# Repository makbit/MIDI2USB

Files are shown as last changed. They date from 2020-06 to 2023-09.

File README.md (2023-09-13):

# MIDI2USB - Free and improved MIDI to USB Converter (v.1.3 Nov 2022)








This device is designed to connect various musical instruments to a PC via the USB Fullspeed port. This is an improved version of the chinese **USB2MIDI** adapter in the same case. There are: 1 IN port, 1 OUT port, 16 channels/instruments, Plug-and-Play feature, Build-in drivers. The adapter is compatible with Windows (32-bit, 64-bit) and was tested with MIDI-OX, MuseScore, Cubase, etc.

The device is based on Silicon Laboratories 8-bit 8051 MCU [EFM8UB20F32](https://www.silabs.com/mcu/8-bit/efm8-universal-bee/device.efm8ub20f32g-qfp32), (avg. price $2). This MCU has Fullspeed USB controller and adjustable internal oscillator (0.25%). You can use any compatible MCU, for example [C8051F380](https://www.silabs.com/mcu/8-bit/c8051f38x/device.c8051f380-gq).

### Advantages of this MIDI2USB adapter:
* Open and clean source code with comments;
* Compliant to hardware and software [MIDI Specification 1.0](https://www.midi.org/specifications-old/item/the-midi-1-0-specification);
* All electronic components are available in your local shop;
* I use it myself.
* MIT License

The [`Hardware`](Hardware) folder contains Eagle CAD 9.0 schematics files, board file and component library. The .BRD file can be sent to your favourite PCB manufacturer. The board schematics can be found in the[`Hardware/Efm8Midi.png`](Hardware/Efm8Midi.png) file.

In the [`Firmware`](Firmware) folder you will find all C-source files for this project. Files from SiLabs SDK are located in the EFM8 subfolder. The project was developed with the [IAR Embedded Workbench IDE 8051](https://www.iar.com/iar-embedded-workbench/#!?architecture=8051). I beleive the source code is compatible with the [Keil uVision PK51](https://www.keil.com/c51/pk51kit.asp).

### Some pictures of this MIDI2USB converter :cool:
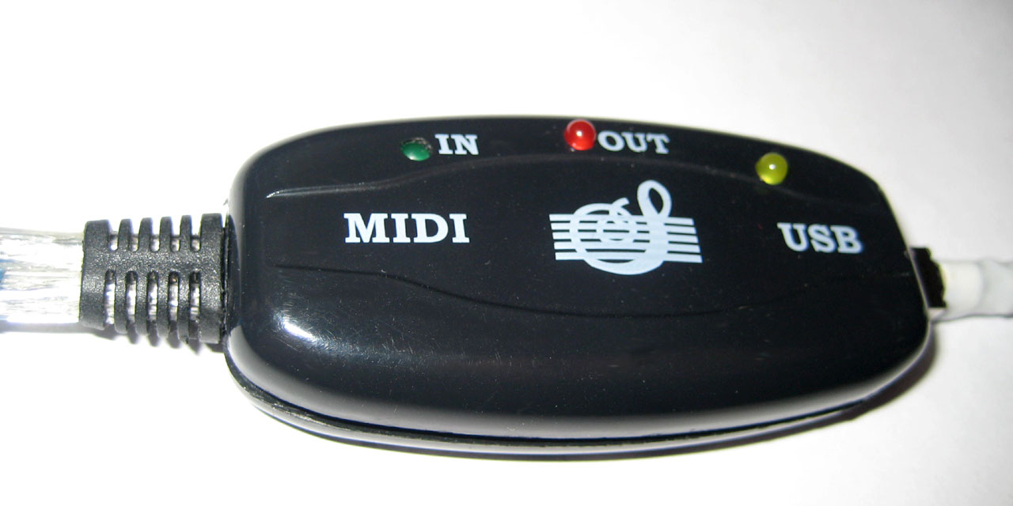
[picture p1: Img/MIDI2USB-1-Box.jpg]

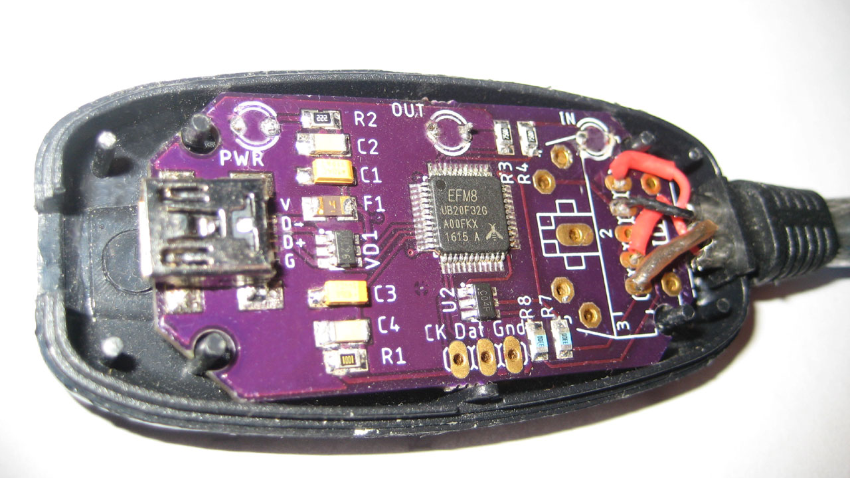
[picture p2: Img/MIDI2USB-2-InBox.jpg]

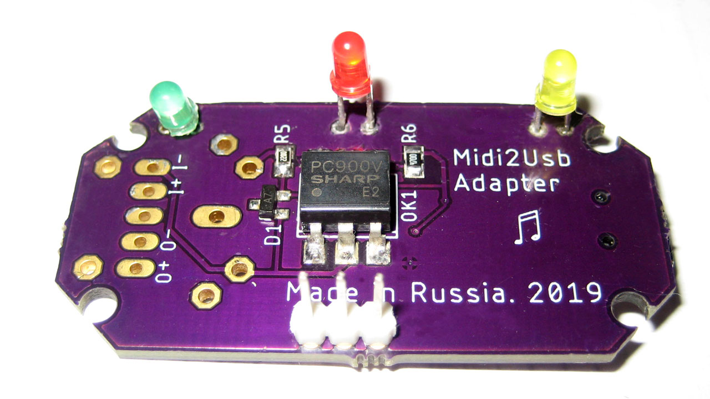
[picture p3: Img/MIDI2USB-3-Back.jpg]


### TODO :pen:
- [x] Switch to UART#1 with FIFO buffer (done);
- [x] Test and improve SysEx handler (done);
- [x] Added Real-Time Message handler (done/test required);
- [ ] Move all components to one side;
- [ ] Add 4-pin header to optionaly solder USB cable;
- [ ] Find a sponsor :smile:

[GitHub readme tips&tricks](https://help.github.com/articles/basic-writing-and-formatting-syntax/)

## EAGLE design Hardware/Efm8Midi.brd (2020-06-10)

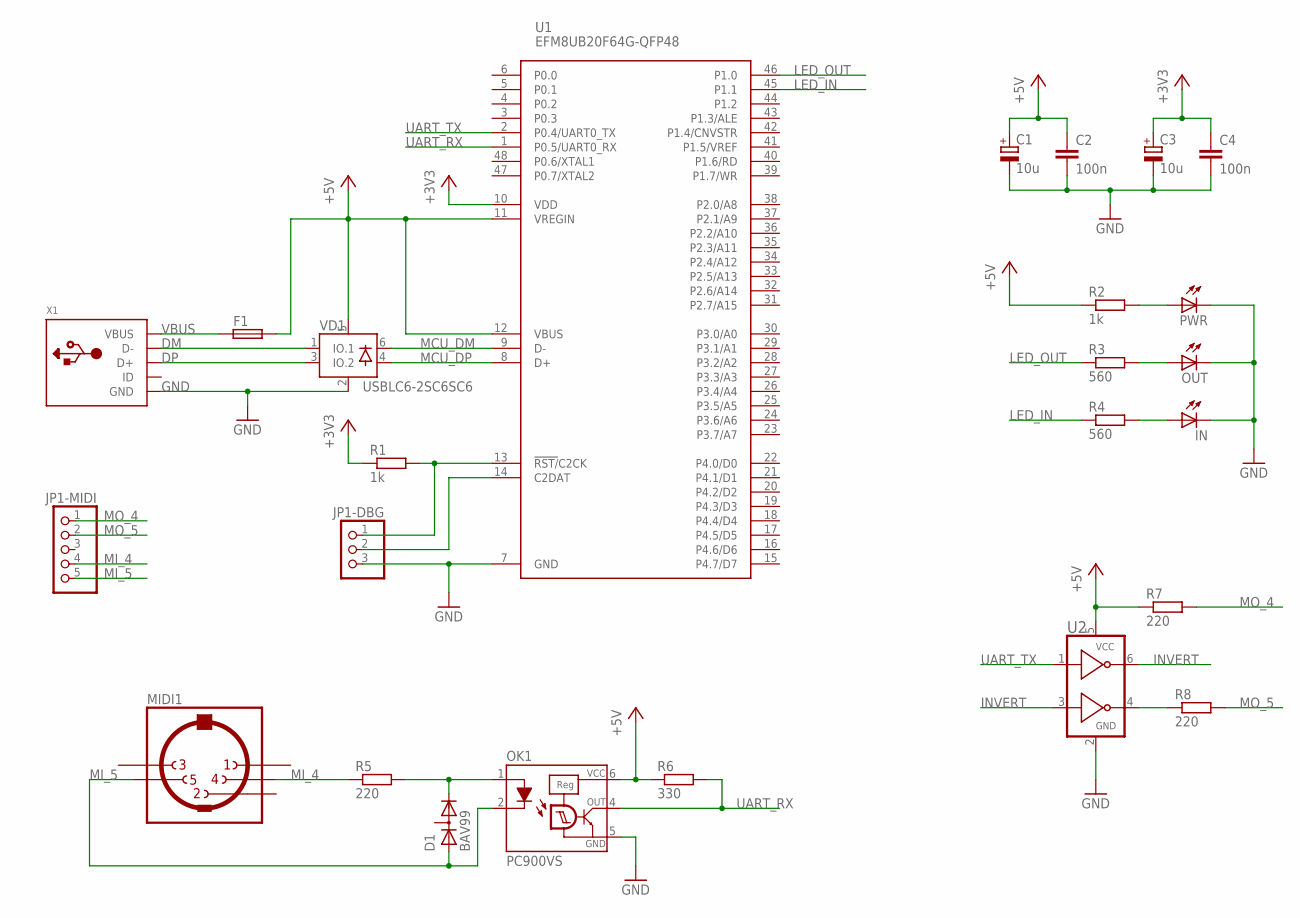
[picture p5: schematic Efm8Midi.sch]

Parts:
C1, C3: 10u; CT3216
C2, C4: 100n; C1206
D1: BAV99; SOT23
F1: MF-NSMF; RCL-1206
IN: LED3MM
JP1-DBG: PINHD-1X3; 1X03
JP1-MIDI: PINHD-1X5; 1X05
MIDI1: MIDIJACK; MIDI-CP-2350
OK1: PC900VS; DIL6-SMD
OUT: LED3MM
PWR: LED3MM
R1, R2: 1k; R0805
R3, R4: 560; R0805
R5, R7, R8: 220; R0805
R6: 330; R0805
U1: EFM8UB20F64G-QFP48; QFP48-7X7-0P5MM
U2: 74LVC2G04SOT-23-6-DBV; SOT-23-290X160-DBV
VD1: USBLC6-2SC6SC6; SOT-23-6L
X1: MINI-USB-B32005-301; USB-MINI-B

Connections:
+3V3: C3.+, C4.1, R1.1, U1.10 (VDD)
+5V: C1.+, C2.1, F1.2, OK1.6 (VCC), R2.1, R6.1, R7.1, U1.11 (VREGIN), U1.12 (VBUS), U2.5 (VCC), VD1.5 (VBUS)
DM: VD1.1 (IO.1), X1.D-
DP: VD1.3 (IO.2), X1.D+
GND: C1.-, C2.2, C3.-, C4.2, IN.K (C), JP1-DBG.3, OK1.5 (GND), OUT.K (C), PWR.K (C), U1.7 (GND), U2.2 (GND), VD1.2 (GND), X1.GND
INVERT: U2.3 (A2), U2.6 (Y1)
LED_IN: R4.1, U1.45 (P1.1)
LED_OUT: R3.1, U1.46 (P1.0)
MCU_DM: U1.9 (D-), VD1.6 (IO_1)
MCU_DP: U1.8 (D+), VD1.4 (IO_2)
MI_4: JP1-MIDI.4, MIDI1.4, R5.1
MI_5: D1.1 (A), JP1-MIDI.5, MIDI1.5, OK1.2 (C)
MO_4: JP1-MIDI.1, R7.2
MO_5: JP1-MIDI.2, R8.2
unnamed: IN.A, R4.2
unnamed: JP1-DBG.1, R1.2, U1.13 (!RST/!C2CK)
unnamed: PWR.A, R2.2
unnamed: R8.1, U2.4 (Y2)
unnamed: D1.2 (C), OK1.1 (A), R5.2
unnamed: JP1-DBG.2, U1.14 (C2DAT)
unnamed: OUT.A, R3.2
UART_RX: OK1.4 (OUT), R6.2, U1.1 (P0.5/UART0_RX)
UART_TX: U1.2 (P0.4/UART0_TX), U2.1 (A1)
VBUS: F1.1, X1.VBUS

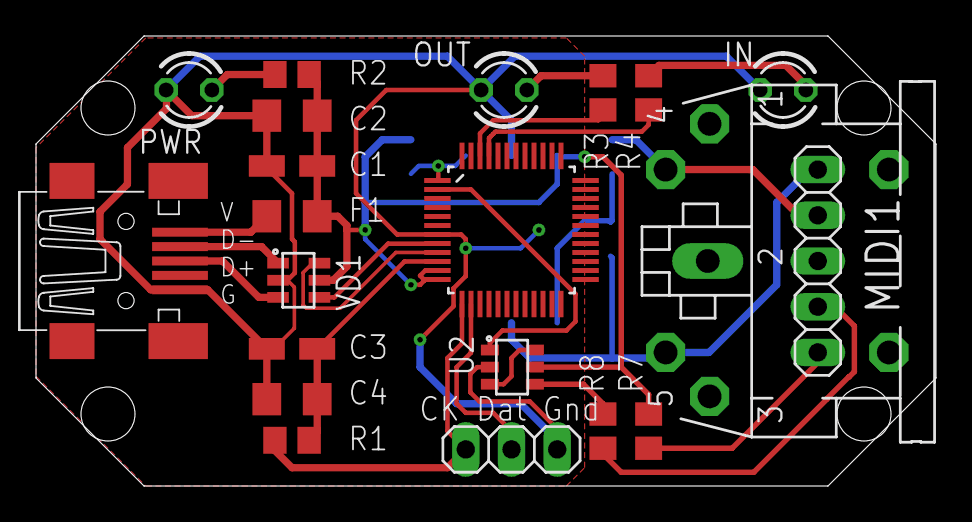
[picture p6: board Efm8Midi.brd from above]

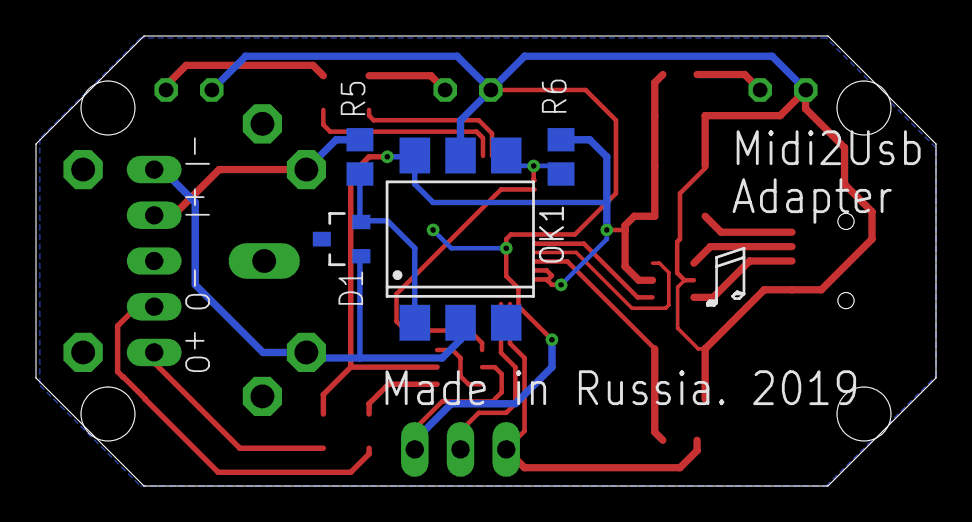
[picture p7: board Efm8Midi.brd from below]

Board: 2 copper layers, 50.0 x 25.0 mm, 25 parts (4 on the bottom side), 24 nets.

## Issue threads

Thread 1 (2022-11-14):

Does not handle Running Status

AmeNote-Michael, 2022-11-14:
System does not properly handle running status - used in many advanced controllers such as Roland, Yamaha, etc.

In MIDI 1.0 specification, see page 5 for more information. See Appendix A-4 for examples.

By not implementing Running Status, missed events do occur on controllers that implement it. For example, on Roland controller I am testing with, striking multiple keys at same time, only one key registered.

AmeNote-Michael, 2022-11-14:
Does not properly handle Real-Time messages where only command/status byte and no data. These events are dropped. These are when command/status byte is masked with value 0xf8. Other than System Reset, messages are not managed and dropped.

Many advanced controllers use active sense (which is debatable if needed on USB, but if just implementing a DIN virtual cable, then may be needed, so just should support) and controller messages like play, stop, continue, etc. are common in many controllers - like DJ controllers.

I have implemented a simple fix where these messages create a new state known as MIDI_STATE_COMMAND_ONLY and then it completes a USB Packet with just command/status populated and all data zero filled, immediately returning to MIDI_STATE_IDLE when complete.

When I have time, I can implement into branch and push back (but will be unable to test on rest of your code as I do not have same processor setup).

makbit, 2022-11-15:
Hello.
You are right. This firmware do not handle Real-time control and SysEx events. My keayboard does not support these messages. I cannot test it and I thought it was not important. Now I will change my mind.
I have found Table 4-2 in MIDI 1.0 spec with Examples of parsed events (page 17). It would be great if you show your 0xF8-command handler.

AmeNote-Michael, 2022-11-15:
This looks promising for a method of providing test scenarios in absence of gear:
https://github.com/jazz-soft/test-midi-files

makbit, 2022-11-16:
Sorry, I do not understand how to test USB device with MIDI files.

AmeNote-Michael, 2023-11-29:
I am no longer actively using your library for a project, thus have not tested further. In my above suggestion, midi files have a set format - the list of files have a variety of known message formats. I would suggest you get / create a small device to use as your test where you parse the files and push in/out MIDI din to your hardware device, testing your device handling. There are a lot of example Raspberry Pi / Pico code out there to take the MiDI files and interact with DIN.

Closed 2023-11-29.

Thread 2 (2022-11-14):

Does not properly handle Real-Time messages

AmeNote-Michael, 2022-11-14:
Does not properly handle Real-Time messages where only command/status byte and no data. These events are dropped. These are when command/status byte is masked with value 0xf8. Other than System Reset, messages are not managed and dropped.

Many advanced controllers use active sense (which is debatable if needed on USB, but if just implementing a DIN virtual cable, then may be needed, so just should support) and controller messages like play, stop, continue, etc. are common in many controllers - like DJ controllers.

makbit, 2022-11-15:
I think you are right. The code in [midi.c Line #80](https://github.com/makbit/MIDI2USB/blob/master/Firmware/midi.c) checks status byte and skips further processing.
` if( MIDI_IS_STATUS(dataRX) )            // System Real Time message`
I would appriciate for a patch. I do not have any DJ device, so I am not sure I can fix it fast.

AmeNote-Michael, 2022-11-15:
Here is some thoughts....

`			case MIDI_CLOCK:
			case MIDI_TICK:
			case MIDI_START:
			case MIDI_CONTINUE:
			case MIDI_STOP:
			case MIDI_ACTIVE_SENSE:
				state = MIDI_STATE_COMMAND_ONLY;
				break;`

`		else if ( state == MIDI_STATE_COMMAND_ONLY )
		{
			// Put MIDI message into the USB stream (zero padding).
			pUsbBuffer->pUSB_MIDI_Buffer[pUsbBuffer->nUSB_MIDI_Buffer_Count++] = 0x0f;		// cable 0, single byte message
			pUsbBuffer->pUSB_MIDI_Buffer[pUsbBuffer->nUSB_MIDI_Buffer_Count++] = dataRX;	// cmd
			pUsbBuffer->pUSB_MIDI_Buffer[pUsbBuffer->nUSB_MIDI_Buffer_Count++] = 0; 		// no data
			pUsbBuffer->pUSB_MIDI_Buffer[pUsbBuffer->nUSB_MIDI_Buffer_Count++] = 0;

			state == MIDI_STATE_IDLE;
		}`

Sorry, best I can do for now.

makbit, 2022-11-16:
Thank you for your support. I have made changes and added Real-Time message handler. It would be great if you or someone else could test new release.

AmeNote-Michael, 2023-11-29:
Sorry, no longer actively using library and unable to test / input further. Wish you luck.

Closed 2023-11-29.

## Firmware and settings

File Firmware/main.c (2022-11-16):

//---------------------------------------------------------------------------//
// Project: Midi2Usb - firmware that connects musical instruments to PC.     //
//                     Converter USB <=> MIDI (in, out).                     //
// File:    Main.c - Firmware entry point, initialization and main loop.     //
// Date:    November 2022, September 2021, May-August 2020, version 1.3      //
// Author:  Maximov K.M. (c) https://makbit.com                              //
// Source:  https://github.com/makbit/Midi2USB                               //
// License: Free for non-commercial use.                                     //
//---------------------------------------------------------------------------//
/*---------------------------------------------------------------------------//
 === Include special header for SiLabs MCU EFM8 ===
 [Options] -> [C/C++ Compiler] -> [Preprocessor]
 $PROJ_DIR$
 $PROJ_DIR$/EFM8/sdk/Device/shared/si8051Base
 $PROJ_DIR$/EFM8/sdk/Device/EFM8UB2/inc
 $PROJ_DIR$/EFM8/sdk/Device/EFM8UB2/peripheral_driver/inc
 $PROJ_DIR$/EFM8/sdk/Lib/efm8_usb/inc
 $PROJ_DIR$/EFM8/sdk/Lib/efm8_assert
-----------------------------------------------------------------------------*/
#include <stdint.h>
#include "globals.h"

// Global variables
volatile SI_SEG_IDATA uint8_t nUsbCount  = 0;      // Data bytes in USB->MIDI
volatile SI_SEG_IDATA uint8_t nMidiCount = 0;      // Data bytes in MIDI->USB
volatile SI_SEG_IDATA uint8_t nMidiRTMsg = 0;      // Real-Time Message (0-none)
SI_SEG_XDATA uint8_t aUsbBuffer [USB_BUF_SIZE];    // Buffer for USB->MIDI
SI_SEG_XDATA uint8_t aMidiBuffer[MIDI_BUF_SIZE];   // Buffer for MIDI->USB
SI_SEG_XDATA uint8_t aMidiRTMsg[sizeof(uint32_t)]; // MIDI_RTMsg->USB

//---------------------------------------------------------------------------//
//                                                                           //
//---------------------------------------------------------------------------//
int main( void )
{
	WDT_Init();                             // Disable WDTimer (not used)
	PORT_Init();                            // Initialize ports (UART, LEDs)
	SYSCLK_Init();                          // Set system clock to 48MHz
	UART1_Init();                           // Initialize UART @31250, 8-N-1
	USBD_Init( &usbInitStruct );            // Initialize USB, clock calibrate
	LED_IN  = true;                         // Blink LED (off after usb-cfg)
	LED_OUT = true;                         // Blink LED (off after usb-cfg)
	IE_EA   = true;                         // Global enable IRQ

	while(1)
	{
		//--- MIDI RTMsg => USB
		// System Real Time messages are given priority over other messages.
		// These single-byte messages may occure anywhere in the data stream.
		if( nMidiRTMsg )
		{
			IE_EA  = false;                 // Begin: Critical section
			aMidiRTMsg[0] = 0x0F;           // Cable=0, Code = 0xF
			aMidiRTMsg[1] = nMidiRTMsg;     // Real-Time Message
			aMidiRTMsg[2] = 0;              // not used
			aMidiRTMsg[3] = 0;              // not used
			if( USB_STATUS_OK==USBD_Write(EP1IN,aMidiRTMsg,sizeof(uint32_t),false) )
			{
				nMidiRTMsg = 0;             // Clear MIDI Real-Time Message
			}
			IE_EA  = true;                  // End of: Critical section
		}

		//--- MIDI => USB
		if( nMidiCount >= sizeof(uint32_t) )
		{
			IE_EA  = false;                 // Begin: Critical section
			if( USB_STATUS_OK==USBD_Write(EP1IN,aMidiBuffer,nMidiCount,false) )
			{
				nMidiCount = 0;             // Reset MIDI data byte counter
			}
			IE_EA  = true;                  // End of: Critical section
			LED_IN = false;                 // Turn off input LED
		}

		//--- USB => MIDI
		if( nUsbCount )
		{
			uint8_t i;
			LED_OUT = true;                 // Turn on Led for New packet
			for(i = 0; i < nUsbCount; i++)  // Process every data byte
			{
				USB2MIDI( aUsbBuffer[i] );  // Convert USB packet into MIDI
			}
			nUsbCount = 0;                  // Reset counter
			USBD_Read(EP2OUT, aUsbBuffer, sizeof(aUsbBuffer), true);
			LED_OUT = false;                // Turn off Led, when done
		}
	}
}

//---------------------------------------------------------------------------//
// USB API Callbacks                                                         //
//---------------------------------------------------------------------------//
#if SLAB_USB_STATE_CHANGE_CB
void USBD_DeviceStateChangeCb(USBD_State_TypeDef oldState,
                              USBD_State_TypeDef newState)
{
	// Entering suspend mode, power internal and external blocks down
	if (newState == USBD_STATE_SUSPENDED)
	{
	}
	// Exiting suspend mode, power internal and external blocks up
	if (oldState == USBD_STATE_SUSPENDED)
	{
	}
	// Start reading, when USB is configured and ready
	if (newState == USBD_STATE_CONFIGURED)
	{
		LED_IN  = 0;                        // Turn off LED
		LED_OUT = 0;                        // Turn off LED
		USBD_Read(EP2OUT, aUsbBuffer, sizeof(aUsbBuffer), true);
	}
}
#endif // SLAB_USB_STATE_CHANGE_CB

//---------------------------------------------------------------------------//
//                                                                           //
//---------------------------------------------------------------------------//
uint16_t USBD_XferCompleteCb(uint8_t epAddr,
                             USB_Status_TypeDef status,
                             uint16_t xferred,
                             uint16_t remaining)
{
	UNREFERENCED_ARGUMENT(epAddr);
	UNREFERENCED_ARGUMENT(status);
	UNREFERENCED_ARGUMENT(remaining);

	if( epAddr==EP2OUT && status==USB_STATUS_OK )
	{
		nUsbCount = xferred;
	}
	return 0;
}

//---------------------------------------------------------------------------//
#ifndef NDEBUG
void slab_Assert()
{
  while ( 1 );
}
#endif

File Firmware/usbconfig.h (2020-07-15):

#ifndef __SILICON_LABS_USBCONFIG_H
#define __SILICON_LABS_USBCONFIG_H

#define SLAB_USB_BUS_POWERED                   1
#define SLAB_USB_FULL_SPEED                    1
#define SLAB_USB_CLOCK_RECOVERY_ENABLED        1
#define SLAB_USB_REMOTE_WAKEUP_ENABLED         0

#define SLAB_USB_NUM_INTERFACES                2
#define SLAB_USB_SUPPORT_ALT_INTERFACES        0

// -----------------------------------------------------------------------------
// Enable or disable each endpoint
// -----------------------------------------------------------------------------
// $[Endpoints Used]
#define SLAB_USB_EP1IN_USED                    1
#define SLAB_USB_EP1OUT_USED                   0
#define SLAB_USB_EP2IN_USED                    0
#define SLAB_USB_EP2OUT_USED                   1
#define SLAB_USB_EP3IN_USED                    0
#define SLAB_USB_EP3OUT_USED                   0
// [Endpoints Used]$

// -----------------------------------------------------------------------------
// Specify maximum packet size for each endpoint
// -----------------------------------------------------------------------------
// $[Endpoint Max Packet Size]
#define SLAB_USB_EP1IN_MAX_PACKET_SIZE         64
#define SLAB_USB_EP1OUT_MAX_PACKET_SIZE        0
#define SLAB_USB_EP2IN_MAX_PACKET_SIZE         0
#define SLAB_USB_EP2OUT_MAX_PACKET_SIZE        8
#define SLAB_USB_EP3IN_MAX_PACKET_SIZE         0
#define SLAB_USB_EP3OUT_MAX_PACKET_SIZE        0
// [Endpoint Max Packet Size]$

// -----------------------------------------------------------------------------
// Specify transfer type of each endpoint
// -----------------------------------------------------------------------------
// $[Endpoint Transfer Type]
#define SLAB_USB_EP1IN_TRANSFER_TYPE           USB_EPTYPE_BULK
#define SLAB_USB_EP1OUT_TRANSFER_TYPE          USB_EPTYPE_BULK
#define SLAB_USB_EP2IN_TRANSFER_TYPE           USB_EPTYPE_BULK
#define SLAB_USB_EP2OUT_TRANSFER_TYPE          USB_EPTYPE_BULK
#define SLAB_USB_EP3IN_TRANSFER_TYPE           USB_EPTYPE_ISOC
#define SLAB_USB_EP3OUT_TRANSFER_TYPE          USB_EPTYPE_ISOC
// [Endpoint Transfer Type]$

// -----------------------------------------------------------------------------
// Enable or disable callback functions
// -----------------------------------------------------------------------------
// $[Callback Functions]
#define SLAB_USB_HANDLER_CB                    0
#define SLAB_USB_IS_SELF_POWERED_CB            0
#define SLAB_USB_RESET_CB                      0
#define SLAB_USB_SETUP_CMD_CB                  0
#define SLAB_USB_SOF_CB                        0
#define SLAB_USB_STATE_CHANGE_CB               1
// [Callback Functions]$

// -----------------------------------------------------------------------------
// Specify number of languages supported by string descriptors.
// -----------------------------------------------------------------------------
// $[Number of Languages]
#define SLAB_USB_NUM_LANGUAGES                 1
// [Number of Languages]$


// -----------------------------------------------------------------------------
// If only one descriptor language is supported, specify that language here.
// If multiple descriptor languages are supported, this value is ignored and
// the supported languages must listed in the
// myUsbStringTableLanguageIDsDescriptor structure.
// -----------------------------------------------------------------------------
// $[USB Language]
#define SLAB_USB_LANGUAGE                      USB_LANGID_ENUS
// [USB Language]$

// -----------------------------------------------------------------------------
//
// Set the power saving mode
//
// SLAB_USB_PWRSAVE_MODE configures when the device will automatically enter
// the USB power-save mode. It is a bitmask constant with bit values:
// USB_PWRSAVE_MODE_OFF       - No energy saving mode selected
// USB_PWRSAVE_MODE_ONSUSPEND - Enter USB power-save mode on USB suspend
// USB_PWRSAVE_MODE_ONVBUSOFF - Enter USB power-save mode when not attached
//                              to the USB host.
// USB_PWRSAVE_MODE_FASTWAKE  - Exit USB power-save mode more quickly, but
//                              consume more power while in USB power-save
//                              mode.
//                              While the device is in USB power-save mode
//                              (typically during USB suspend), the
//                              internal voltage regulator stays in normal
//                              power mode instead of entering suspend
//                              power mode.
//                              This is an advanced feature that may be
//                              useful in certain applications that support
//                              remote wakeup.
//
// -----------------------------------------------------------------------------
// $[Power Save Mode]
#define SLAB_USB_PWRSAVE_MODE                  USB_PWRSAVE_MODE_OFF
// [Power Save Mode]$
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

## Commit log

2020-08-20 Device images
2020-08-20 Version 0.2 (August 2020)
    Spaces/Tabs fix
    [midi.c]
2021-09-27 No more magic constants + UART1 (2021.09.25)
2021-09-27 Now we use UART1 with FIFO (2021.09.25)
2021-09-27 SysEx support and UART1 with FIFO (2021.09.25)
